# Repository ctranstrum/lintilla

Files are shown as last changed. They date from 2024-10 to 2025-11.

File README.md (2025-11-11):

# Lintilla Keyboard

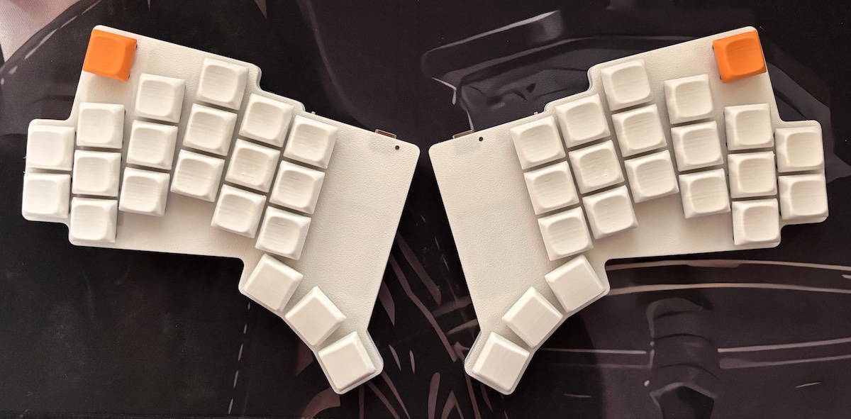
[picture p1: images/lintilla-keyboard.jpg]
Lintilla Keyboard


## Features

- 42 key wireless split ergo keyboard with aggressive pinky stagger, splay, and "reachy" thumbs
- Seeed Studio [XIAO BLE][xiao] microcontroller
- Choc v1 hotswap switches
- "Relaxed" (18.5x18) choc spacing: a compromise between MX (19x19) and choc (18x17)
- 7mm low-profile "snug sandwich" case with no exposed components on top or bottom
- [RGB LED status][rgbled] visible on the top of the case
- Wireless-first design using [ZMK][zmk] [firmware][firmware] (including [ZMK Studio][studio])
- Jumperless [reversible](images/pcb-allitnil.jpg) [PCB](images/pcb-lintilla.jpg) designed with [ergogen][ergogen]
- Soldering is simple: SMD components all on a single side of the board for each half
- Internal space (5.4 x 24 x 34 mm) for a "large" 502030 250mAh battery
- Licensed under the [CERN Open Hardware License v2][ohl]
- All source files available, so you can tweak the design if needed

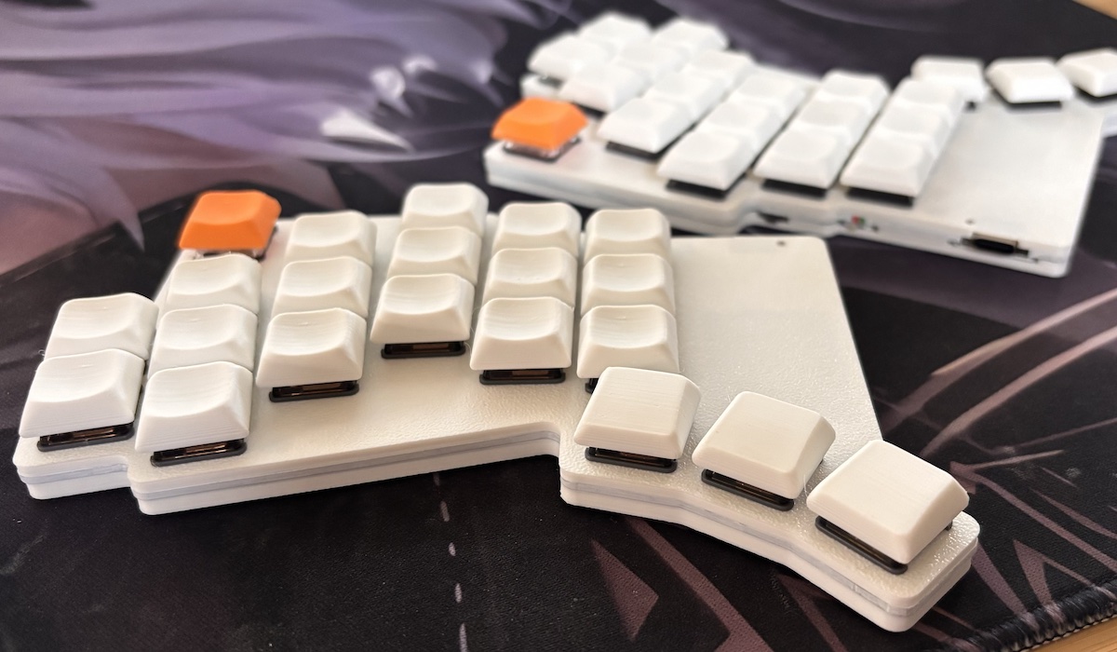
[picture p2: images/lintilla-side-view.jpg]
Lintilla side view


## Design goals

- Low cost wireless
  - xiao ble is only $10 per controller compared to $25 for the nice!nano
  - Reversible PCB for the cheapest manufacturing option (I ordered a set of 5 boards, the minimum order, for under $10)
  - Big battery and an option for a dongle, so you can [run for months without recharging][batteryestimate]
- Ergonomic design for the ultimate comfort
  - split keyboard means you can place each half where it best works for you
  - keys are placed where (my) fingers at rest naturally fall
    - when fingers extend, they splay, so the keys also splay outward to follow the fingers
    - the pinky is shorter than the other fingers, so the pinky keys are placed lower to match
    - unlike most ergonomic boards, the thumb doesn't have to tuck below the palm to reach the thumb keys
  - includes all source files, so if your fingers are slightly different, with a little work you can adjust the keyboard to fit you exactly
- Low profile 3D printable case
  - case is only 7mm high and each side comes in two separate pieces, each largely flat on one side for easy FDM printing with minimal fuss
  - bumpons are inset into the case 1mm to minimize their height; they add only 1/2mm in height
  - choc v1 hotswap switches are some of the shortest commonly available
- Hotswappable
  - keycaps and switches can be easily removed and exchanged so you can fine tune the feel
  - the case is designed to hold tight to the switches, while offering a switch-puller groove that allows for safe and easy removal
- Electrostatic protection
  - unlike other ultra-low-profile cases, no electronics are exposed on either the bottom or the top of the case
  - on the side of the case, the reset button and power switch are available, and the usb port is accessible

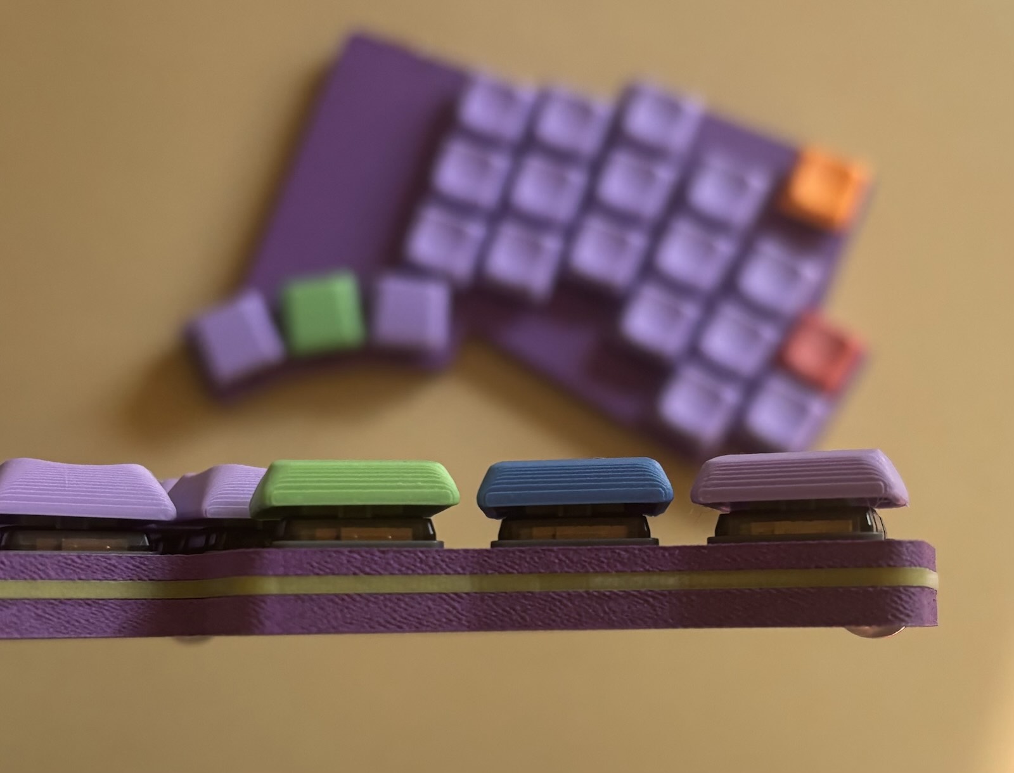
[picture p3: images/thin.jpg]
low profile case


## Build Your Own

Think the Lintilla might be right for you? Print out the [fit guide][fitguide] to see how it feels under your fingers.

Want to build one? You will need to obtain the following components:

| Qty | Description |
| --- | --- |
| 2 | identical [Lintilla PCBs][pcb] (can be printed by uploading the [zip file][pcb] to [JLC][jlc]) |
| 4 | [3D printed cases][case], top and bottom for each half |
| 2 | [XIAO BLE][xiao] processors |
| 2 | [Panasonic EVQ-PUC02K momentary switches][reset] for the reset button |
| 2 | [Alps SSSS811101 SPDT slide switches][power] for the battery on/off |
| 2 | [3.7v 250mAh 502030 rechargeable LiPo batteries][battery] (max internal space: 5.4x24x34mm) |
| 42 | SOD-123 [1N4148W SMD diodes][diodes] |
| 42 | Kailh [Choc Hot Swap Sockets][sockets] |
| 42 | [Choc v1 switches][switches] of your choice |
| 42 | [Choc v1 keycaps][keycaps] of your choice (note: full MX-sized keycaps will be too big) |
| 8 | [M2 hex nuts][hexnuts] |
| 8 | [M2 x 6mm countersunk screws][screws] |
| 8 | [6mm x 1.5mm bumpons][bumpons] |
| ~5-6mm | [1.75mm transparent 3D printer filament][filament] for the "fiber optic" led light guide |

Once you have these items, you can follow the instructions in the [Build Guide][buildguide].

## Firmware

After you build the keyboard, you will need the [ZMK firmware][firmware].

## What's this about a dongle?

The Lintilla keyboard, with its [LED indicator][rgbled], is perfectly capable of running without a dongle.
With a 250mah battery, the central half should last about 2 months between charges, and the peripheral about 4-6 months.

Some people prefer to use a [dongle][dongle], though, both to allow both halves to last longer between recharging,
as well as to provide additional feedback on the battery and bluetooth status and currently active layer and modifiers.

I have tested the Lintilla with the following dongles, though you should be able to get any ZMK-compatible dongle to work with it:

- The fancy [Prospector Dongle][prospector]
- The more traditional [OLED Dongle][oled]

Note that while the Lintilla keyboard uses the XIAO BLE as its processor, you can use any bluetooth-capable ZMK-compatible processor
on the dongle. If you found a dongle you like, but it uses the nice!nano processor, for example, it should work just fine with Lintilla.

## Credits and inspiration

- [ZMK][zmk]: for the firmware
- [Ergogen][ergogen]: for the tools to quickly iterate over the design
- [Ergonaut One][ergonautone]: for the elegant approach to a xiao-based reversible PCB
- [Klor][klor]: for the almost-perfect key layout

## Descendants

After I used the Lintilla for about three months, I realized that for me, the design had a few flaws:

- The case can bend a bit on the outside edge of the controller; an extra screw there would have helped with that
- Constantly adjusting the location of each split half as I moved around while typing was annoying
- I felt like the layout had too many keys intended for use by the pinky, causing pain after long typing sessions
- My thumbs aren't smart enough to use three keys each; I kept pressing the wrong thumb key, even after three months of use

To address these concerns, while still preserving the basic structure of the Lintilla key layout,
I designed the [Charlieflex keyboard][charlieflex], an ergonomic unibody keyboard with between 30 to 32 keys.

I've been using a 31-key version of Charlieflex for over half a year now, and I'm very happy with it.

## In the wild

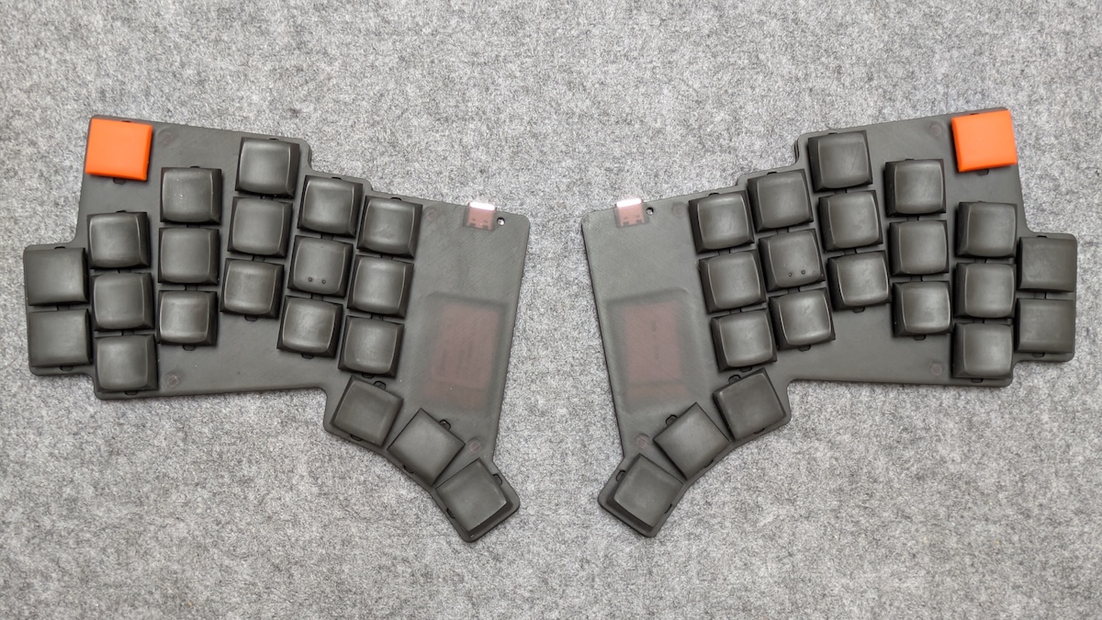
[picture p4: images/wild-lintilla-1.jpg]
first Lintilla in the wild


cairn's Lintilla build, using JLC Black Resin for the case, with Nocturnal switches and Chicago Steno keycaps.

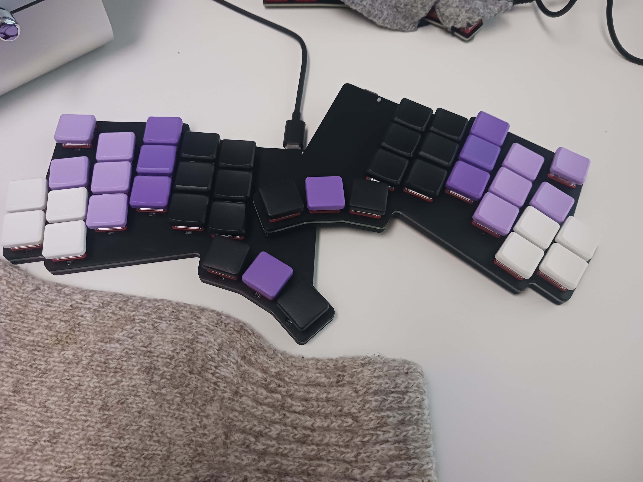
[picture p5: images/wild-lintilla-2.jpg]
kovas's Lintilla


kovas's Lintilla, see some more details and pictures on [his website](https://kovasap.github.io/docs/lifestyle-optimizations/keyboards-and-typing/#lintilla).

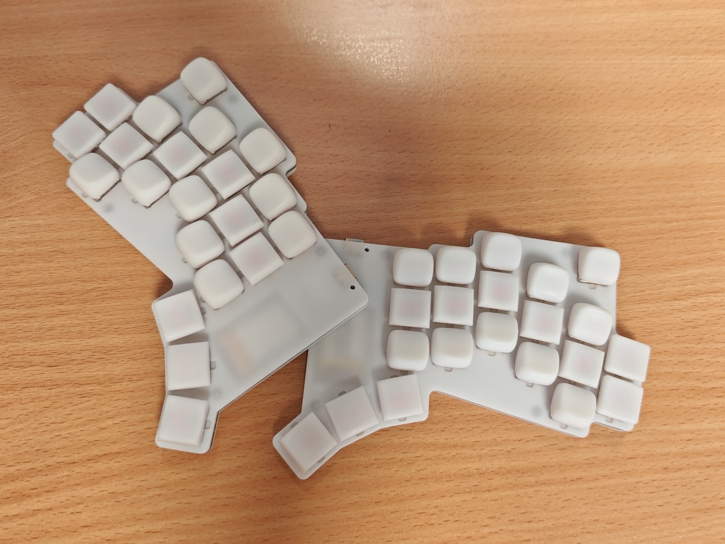
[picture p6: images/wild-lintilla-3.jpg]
Kris' Lintilla


Kris's Lintilla.

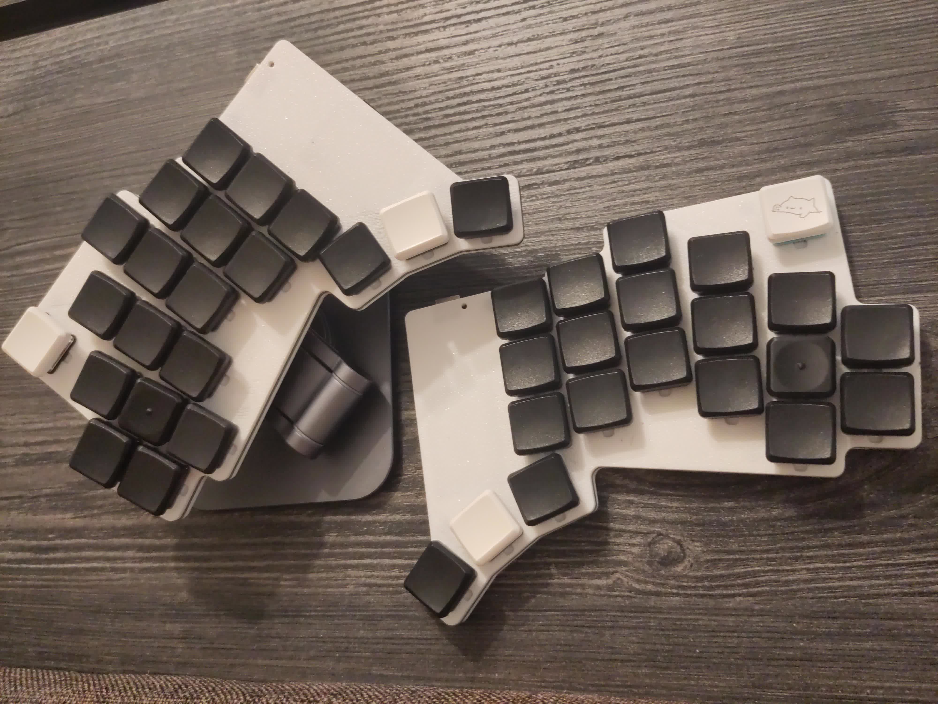
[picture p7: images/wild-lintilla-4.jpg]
Optional's Lintilla


Optional's Lintilla, read some more details on [her blog](https://blog.optional.page/misc/better-keyboard#interlude-my-experience).

---

Did you build a Lintilla? Send me a photo, and I'd be glad to feature it here.

[battery]: https://ydlbattery.com/products/3-7v-250mah-502030-lithium-polymer-ion-battery
[batteryestimate]: https://zmk.dev/power-profiler
[buildguide]: BUILD.md
[bumpons]: https://www.walmart.com/ip/Small-Door-Bumpers-Self-Adhesive-Clear-Rubber-Feet-Tiny-Bumpons-1-4-Diameter-X-1-16-Thick-100-Pack-u2026/2377364014
[case]: cases/
[charlieflex]: https://github.com/ctranstrum/chuck
[diodes]: https://typeractive.xyz/products/smd-diodes
[dongle]: https://zmk.dev/docs/development/hardware-integration/dongle
[ergogen]: https://ergogen.xyz
[ergonautone]: https://ergonautkb.com/docs/keyboards/ergonaut-one/intro/
[filament]: https://gizmodorks.com/nylon-filament-200-g-spool/
[firmware]: https://github.com/ctranstrum/lintilla/tree/zmk
[fitguide]: images/fit-guide.pdf
[hexnuts]: https://www.getfpv.com/m2-black-metal-hex-nut-set-of-8.html
[jlc]: https://jlcpcb.com
[keycaps]: https://lowprokb.ca/collections/keycaps/products/ldsa-low-profile-blank-keycaps
[klor]: https://github.com/GEIGEIGEIST/KLOR
[ohl]: LICENSE.txt
[oled]: https://github.com/englmaxi/zmk-dongle-display
[pcb]: pcb/lintilla-gerbers.zip
[power]: https://typeractive.xyz/products/power-switch
[prospector]: https://github.com/carrefinho/prospector
[reset]: https://typeractive.xyz/products/reset-button
[rgbled]: https://github.com/caksoylar/zmk-rgbled-widget
[screws]: https://monsterbolts.com/products/mach-phil-flat-a2-m2?variant=21222571802707
[sockets]: https://typeractive.xyz/products/hotswap-sockets?variant=45742200324327
[studio]: https://zmk.dev/docs/features/studio
[switches]: https://lowprokb.ca/collections/switches/products/ambients-silent-choc-switches
[xiao]: https://wiki.seeedstudio.com/XIAO_BLE/
[zmk]: https://zmk.dev

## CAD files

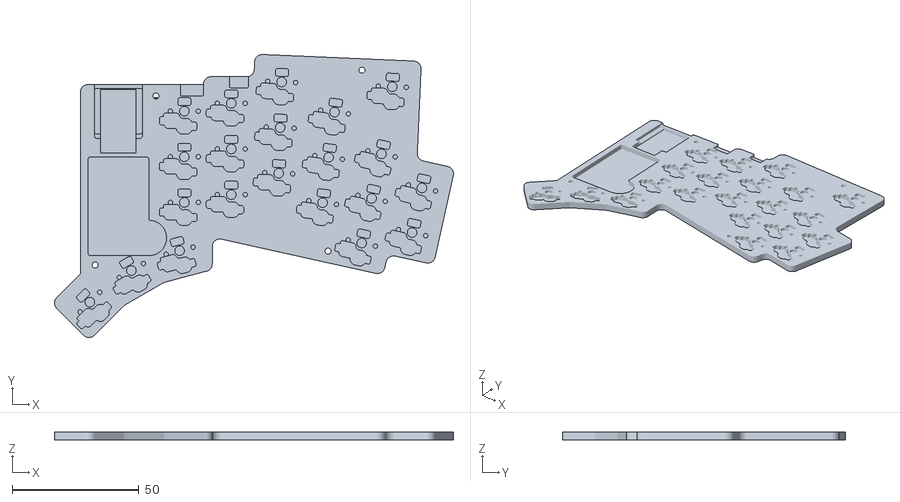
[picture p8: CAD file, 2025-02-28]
cases/bottom_right.stl
157.3 x 111.6 x 3.20

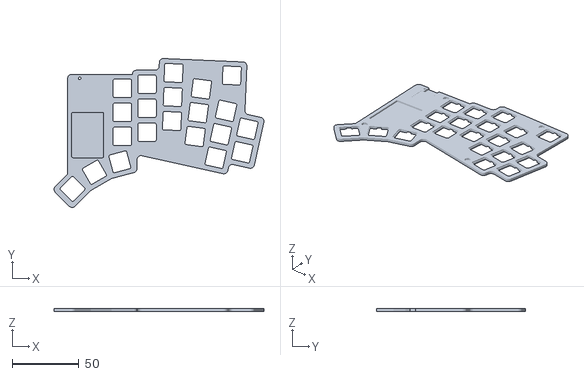
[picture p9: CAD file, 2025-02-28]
cases/top_left.stl
157.3 x 111.6 x 2.20

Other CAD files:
cases/top_left_reverse.stl
cases/top_right.stl

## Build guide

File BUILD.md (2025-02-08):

# Lintilla Build Guide

If this is your first time building a custom keyboard,
you should do two things before attempting this build.

- watch a few [soldering][how-to-solder] [tutorials][soldering101]
- read through a detailed build guide like
  the one for the [splitkb.com Aurora Series][splitkb-build-guide]

The remainder of this build guide will assume a basic familiarity with the process
and will only hit upon specific items that may be different or important to note while
building the Lintilla.

## Useful equipment

You should ideally have access to:

- a [soldering iron][pinecil]
- some [good quality solder][kester]
- a decent hands-free magnifying glass
- precision tweezers
- wire cutter / stripper
- isopropyl alcohol and an old toothbrush

## Getting the PCB

The PCB can be easily ordered from a circuit board manufacturer with an online store.
I used [JLC][jlcpcb] because--at least at the time of my order--their prices are unbeatable.

To order, you can simply upload the [gerber zip file][gerber] to their website,
accept all of the defaults, and wait a week or two for the boards to arrive.

Since the PCB is reversible, in theory you could order just two of them, and you'd be able
to build a complete keyboard. However, the minimum order at JLC is 5 copies, so you'll likely end up
with enough PCBs to complete two and a half keyboards. I don't really have any advice for what to do with
half a keyboard, but if you make two keyboards, you could give one to a friend!

A few items that you may want to customize:

- the color of the board; I printed mine in white, but whatever color you pick, the edges of the PCB will still be a little greenish
- you can choose to hide the JLC order number, or place it on the board where I've included the required order number string
- HASL can be lead-free if you are also using lead-free solder, or you can splurge for ENIG, but it's definitely not required

## Printing the case

If you don't have access to a 3D printer, you can also print your case at [JLC][jlc3dp].
I've had complicated boards printed in "Imagine Black" resin before, and been very impressed with the results.

However, I designed this case to be easy to print yourself on an FDM printer at home.
I printed mine using PLA, but you may want to consider PETG if you are planning to travel with
the keyboard and may at some point leave it in a hot car.

The case comes in [four separate files][case], a top and bottom for each half.

There are a few spots on the case where there is a small overhang that could cause problems on an untuned printer.
This is for the bumpon indentations on the bottom of the case, and for the switch-puller access on the top of the case.
I chose to enable supports for these sections, and had to gently remove the extra support material after each print,
but I felt like the print had higher quality this way.

## Soldering the components to the PCB

Once you've got your PCB and your components in hand, the exciting part of building can begin!

### All components are soldered on the same side of the board

Unlike many other custom keyboards, the Lintilla is designed so that all components are
soldered on the **bottom** of the circuit board. This makes the top of the board as low profile
as possible and makes it easy to know where each component goes.

While the PCB is reversible for the lowest cost manufacturing,
the silkscreen on the top of the board is different from the bottom,
so that when you are soldering components on the side labeled "Lintilla"
you are working on the right half of the keyboard,
and when you are soldering components on the side labeled "Allitnil"
you are working on the left half of the keyboard.

| Lintilla (right half) | Allitnil (left half) |
| --- | --- |
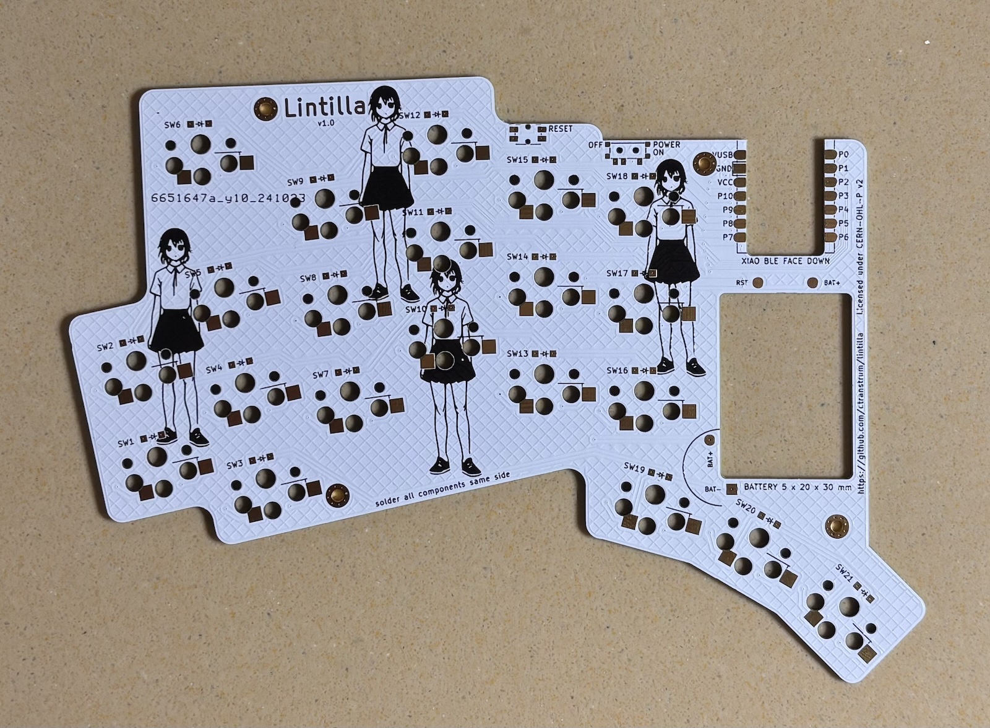
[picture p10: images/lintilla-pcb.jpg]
Lintilla
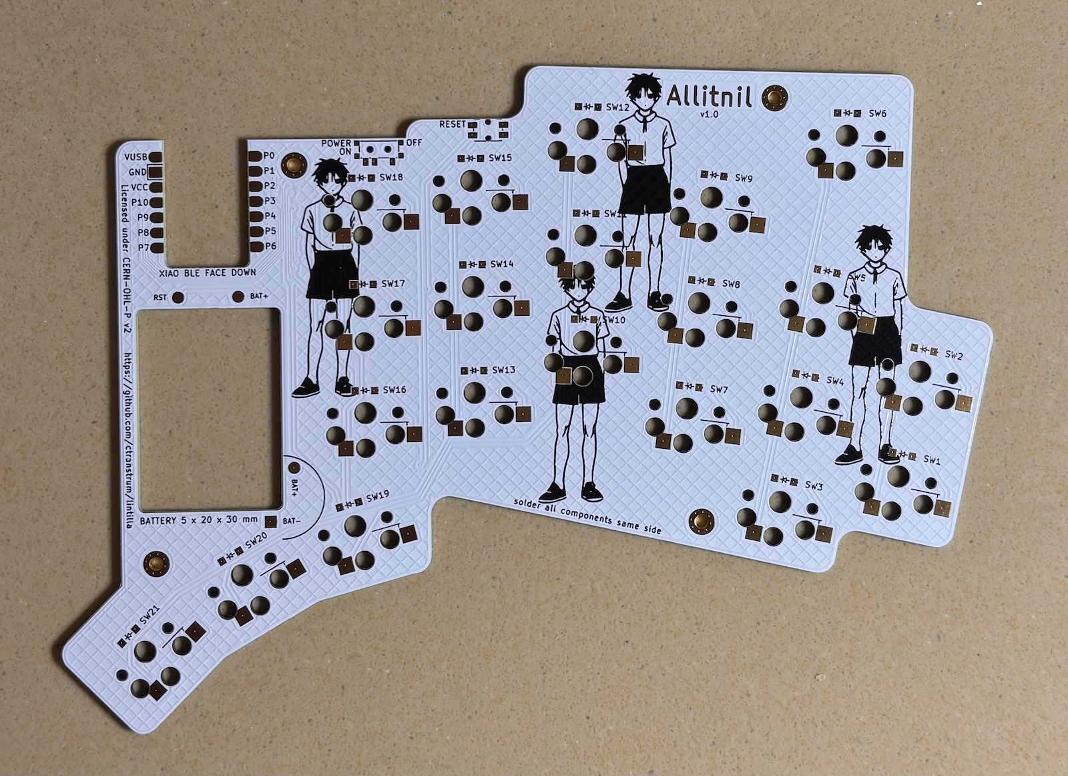
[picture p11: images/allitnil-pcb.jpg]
Allitnil
|  |  |

### Diodes only work one direction

Start with the diodes. Note that diodes only work in one direction,
so it's important that you align the line on the diode with the silkscreen line
on the PCB. It can sometimes be hard to see the line on the diode, so you may have
to look at it under a magnifying glass and/or with the light striking the diode at
an angle to see it well.

All the diodes are oriented the same way on each half of the PCB. That is to say,
when you are soldering on "Lintilla", all the lines on the diodes will be on the right,
and when you are soldering on "Allitnil", all the diode lines will be on the left.

| Lintilla diodes | Allitnil diodes |
| --- | --- |
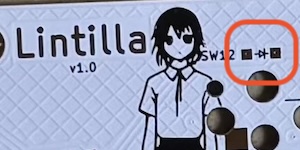
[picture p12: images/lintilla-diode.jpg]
Lintilla diode alignment
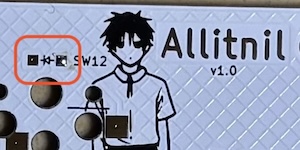
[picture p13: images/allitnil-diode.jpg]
Allitnil diode alignment
|  |  |

To solder a surface mount diode, I find it easiest to first add a little solder to one
of the pads on the PCB, then using a pair of tweezers move the diode into position as I
reheat the solder, and then remove the soldering iron while still holding the diode in
position so the solder can cool. Once I am satisfied that the diode is correctly in
place and flat against the PCB, I then solder the other leg of the diode.

Note that for the case to fit properly, it is important that each diode be centered in
its position and flat against the board. If it is too far out of position or sitting at
an angle on the board, the case may not fit.

### Hotswap sockets also need to be aligned

Next step is the hotswap sockets. Although electrically they will work even if installed
the wrong way, in order to ensure that the case fits correctly,
it is important to look at the line on the silkscreen and align the hotswap
socket so that the corner with the right angle is oriented to the line on the PCB.

In the following picture, the blue box on SW19 shows the silkscreen line before
a hotswap socket is installed, the green box on SW20 shows a hotswap socket in the
correct orientation where the silkscreen line is mostly hidden by the straight lines of
the top edge of the socket, and the red box on SW21 shows an incorrectly oriented
hotswap socket, where the silkscreen line is clearly visible poking out around the
angled edges of the socket.

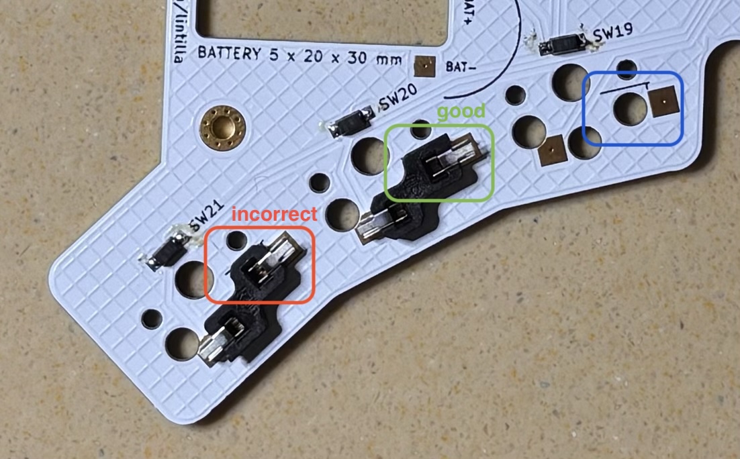
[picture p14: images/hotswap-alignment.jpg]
hotswap socket orientation


To install a hotswap socket, set the socket into place in the PCB, double check the alignment, and
then heat one pad and feed solder into the hollow of the socket until it's pretty much filled up, noting that
the hotswap socket will take a **LOT** more solder than used for the diodes. Repeat for the other leg.
Note that you need to be careful not to use so much solder that it flows outside of the socket footprint,
while still ensuring that you still have enough to allow for a strong bond to form,
which will help provide strength to the socket for inserting and removing the switches,
If you use too much solder so that it spills out of the socket, the case will not fit correctly.

### Power switch and reset switch

The power and reset switches are very similar. The PCB has tiny holes to help with the alignment
of these switches, and just like with the SMD diodes, the trick is to start with a little solder
on one of the pads, then use tweezers to keep the switch in place and/or fix its alignment
while reheating the solder. Once one leg is firmly in place and the alignment is correct, you can
solder the remaining legs.

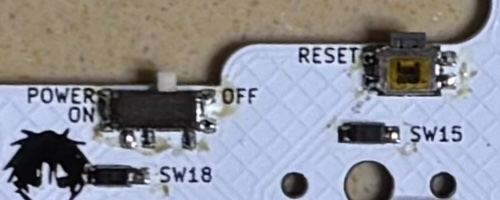
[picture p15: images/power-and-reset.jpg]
power and reset switches


Note that the four legs on the left and right edges of the power switch are not electrically important; they
serve to provide strength to the switch to withstand the pressure of turning the switch on and off.
So if you accidentally join these legs together with solder, you don't need to try to remove the joining solder.

For the reset switch, however, it is important that the top and the bottom legs do not have a solder bridge.

Again note that while there is a little extra space around the pad for the solder, in order for the case to fit
correctly, it is important that you do not have too much extra solder going outside of each pad or above the switches.

Once you have soldered the power switch onto the board, make sure to leave it in the "OFF" position for the duration
of the soldering. Note that when the power switch is pushed toward the microcontroller, it is "ON"
and when it is pushed away, it is "OFF".

### Microcontroller

Now that all the other components are soldered to the board, it is time to address the microcontroller.

The board has been designed so that the majority of the height of the microcontroller is using the same vertical
space as the PCB itself, so it's a bit unconventional, but the microcontroller needs to be soldered upside down to the board.

Note that the height of the components on the XIAO is higher than the thickness of the PCB,
so in order for the XIAO to lay flat during the soldering process, the PCB will need to be placed on something flat
with the place where the XIAO sits extended off over the edge so that there is room for the XIAO.
I used some of the extra PCBs for this, simply stacking two spare PCBs below the one I was soldering.

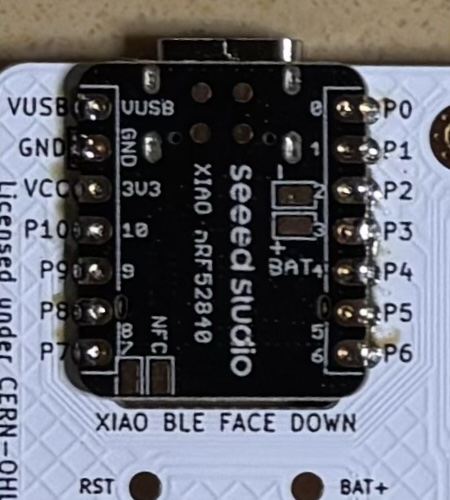
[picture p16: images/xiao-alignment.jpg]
XIAO Microcontroller


The alignment of the microcontroller is a little tricky.
There are lines on the PCB where the XIAO edges should go,
but getting it to stay in place while soldering it is a bit of a challenge.
My technique is similar to that of a diode:
put a little solder on one of the corner pads of the PCB,
and use tweezers or a finger (far from the heat of the soldering iron!)
to steady the board while reheating the solder.
I usually have to do this three or four times to get the board perfectly aligned.
While there is a little leeway on an exact fit,
you should take care to get it as close as possible.
The top edge of the XIAO should be even with the edge of the PCB,
and along both sides of the XIAO you should be able to see an equal amount of each pad sticking out.

Once one corner is soldered and the alignment is looking good,
solder the opposite corner to firmly fix it in place,
and then solder each remaining pad one by one,
placing the tip of the soldering iron on the visible portion of
the PCB pad and against the side of the XIAO's castellated pad.
Take care not to allow the solder to spill out of the side of the pad or above the XIAO,
but you should be able to see solder coating the bottom of the pad through each hole in the XIAO,
and it's okay if that solder fills up some of each hole as well.

### Battery

Now for my least favorite part. First double check that the switch is in the "OFF" position.
Place the battery into the battery cutout with its wires pointing toward the semicircle
in the silkscreen. That semicircle indicates the amount of room available for the wires.

You will need to cut, strip, and solder the battery wires to the board. When cutting the battery wires:

- cut and solder one at a time (you do not want the exposed portion of the wires to touch or you will destroy the battery)
- put electrical tape over any exposed wire you aren't working on, for extra precaution
- leave enough length to get a little bend in the wire, but not so much that the wire goes outside the semicircle, as shown in the picture
- keep the remaining wire after it's cut; you'll use it on the next step
- make sure to solder the red wire to BAT+ and the black wire to BAT-

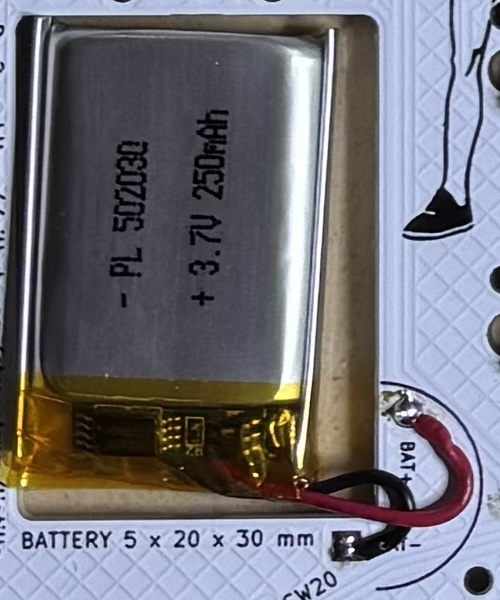
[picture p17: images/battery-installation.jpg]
battery wire soldering


Then, with the remaining wire that was cut from the battery,
connect the pads on the underside of the XIAO to the pads on the PCB.

Be very careful to cut these wires to the exact length needed.
You don't want them too long. And too short is also obviously not going to work.
I speak from experience here.

Both the XIAO and the PCB have a silkscreen for the BAT+ wire. However, the XIAO does not have any mark for the RST pad.

The reset pad on the XIAO is the lower right pad of the four circular pads near the USB port.

When connecting these wires, try to go straight up from the PCB onto the back of the XIAO before going left or right.
The bluetooth antenna is located in the lower middle section of the XIAO,
and a wire there could slightly interfere with the bluetooth signal.

Also note that the XIAO BAT+ and BAT- pads are **really** close together, and you don't want to bridge these,
so be extra careful when soldering the BAT+ pad, and don't turn the power switch back on until you are certain
you haven't inadvertently connected these two pads.

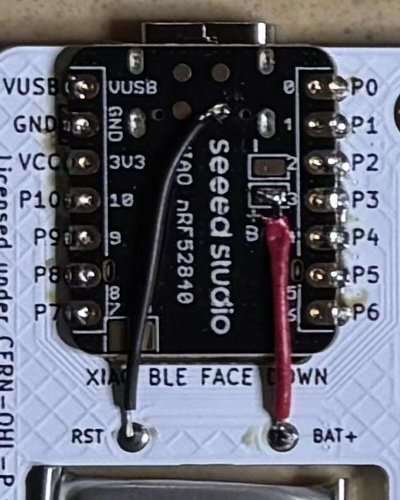
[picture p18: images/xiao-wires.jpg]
xiao back pad wires


### Clean the flux

Now that all the components are soldered onto the board and the battery is connected, take a moment to admire your work,
then clean the flux from the board using an old toothbrush and some isopropyl alcohol. It doesn't have to be perfect.

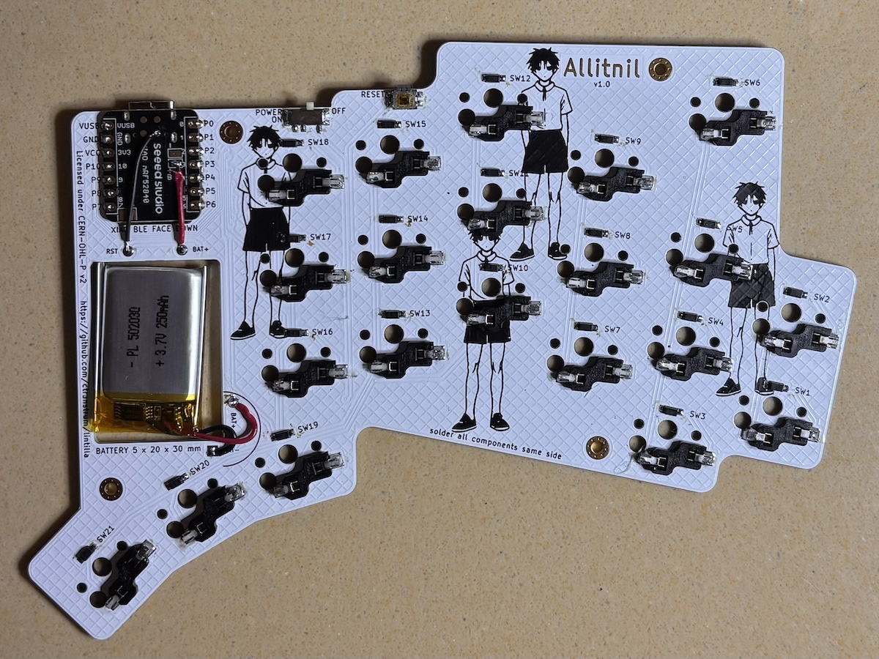
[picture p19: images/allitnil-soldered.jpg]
Allitnil soldered and cleaned


Also take a moment to examine each solder joint
to ensure that you don't have extra blobs of solder
that might interfere with the case.

If you do, you can remove these with a clean soldering iron and a little soldering wick.

Flip the board over and make sure no solder sneaked through any of the vias.
If it did, a moment with a hot iron can clean these up as well.

## Assemble the PCB into the case

Now it's time to put the case together! You're almost there!

### Slide the "fiber optic" light guide in place

Take the section of translucent printer filament and slice a tiny section about 2.5 to 3mm in length.
This can be hard to do because it's so tiny and it will try to fly away and hide in the carpet or behind a bookshelf.
I speak from experience.

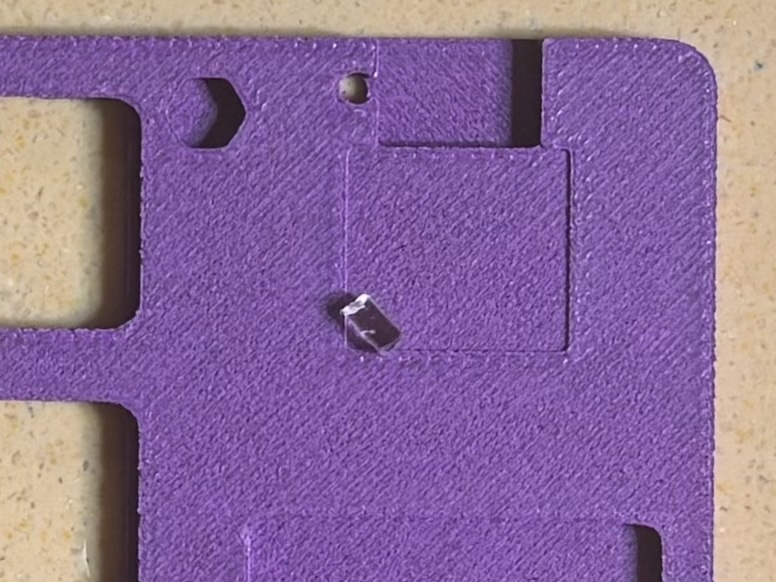
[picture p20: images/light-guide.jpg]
filament cut and ready for insertion


Once you have this piece cut (and you still know where it is), use a pair of tweezers to coax it into the hole in the top case.

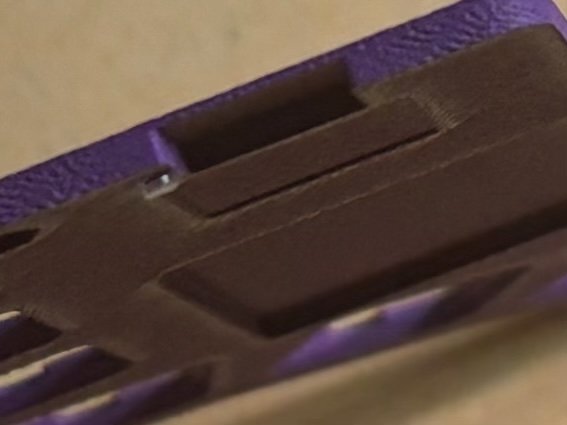
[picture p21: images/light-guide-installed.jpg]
filament in place


It should extend out a little bit below the case, and if it pokes out a bit above the case as well, that's okay, too.
When the case is fully assembled, you can push down gently on it to get it as low as possible.
On my board, it sticks up about a quarter of a millimeter, and that allows the light to be very visible.

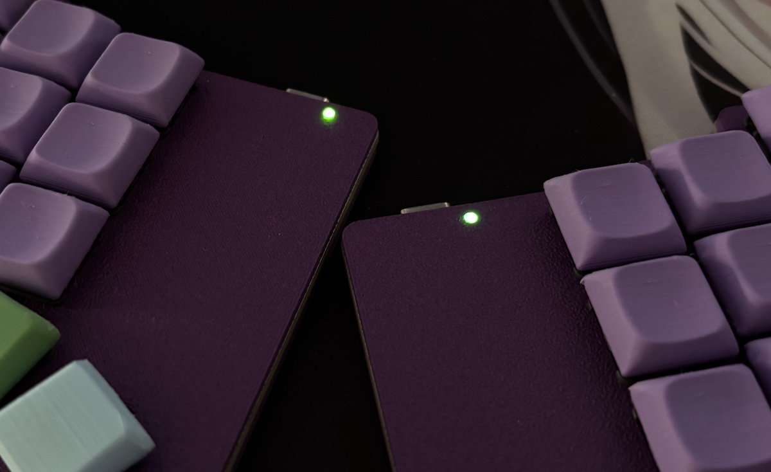
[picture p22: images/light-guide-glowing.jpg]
filament in action


### Use the nuts and screws to assemble the case to the PCB

Place the four nuts into the cutouts in the top case.

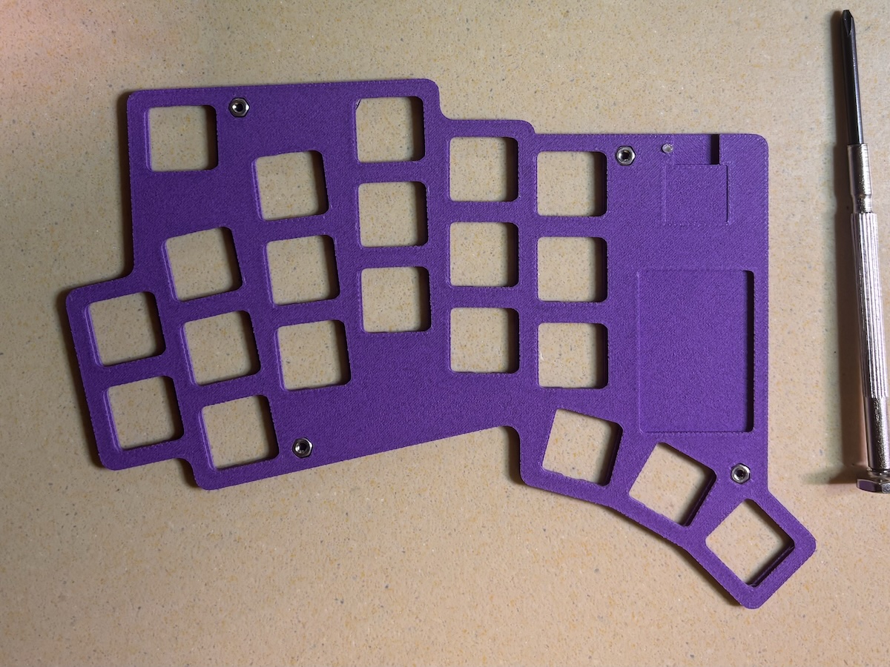
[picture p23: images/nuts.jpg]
nuts in place


Then place the PCB onto the case, components facing away from the top case, and align the edges.
The xiao and the battery should slide easily into the hollows prepared for them and help with alignment.
Put the bottom case on top, and use four screws to secure it to the PCB.

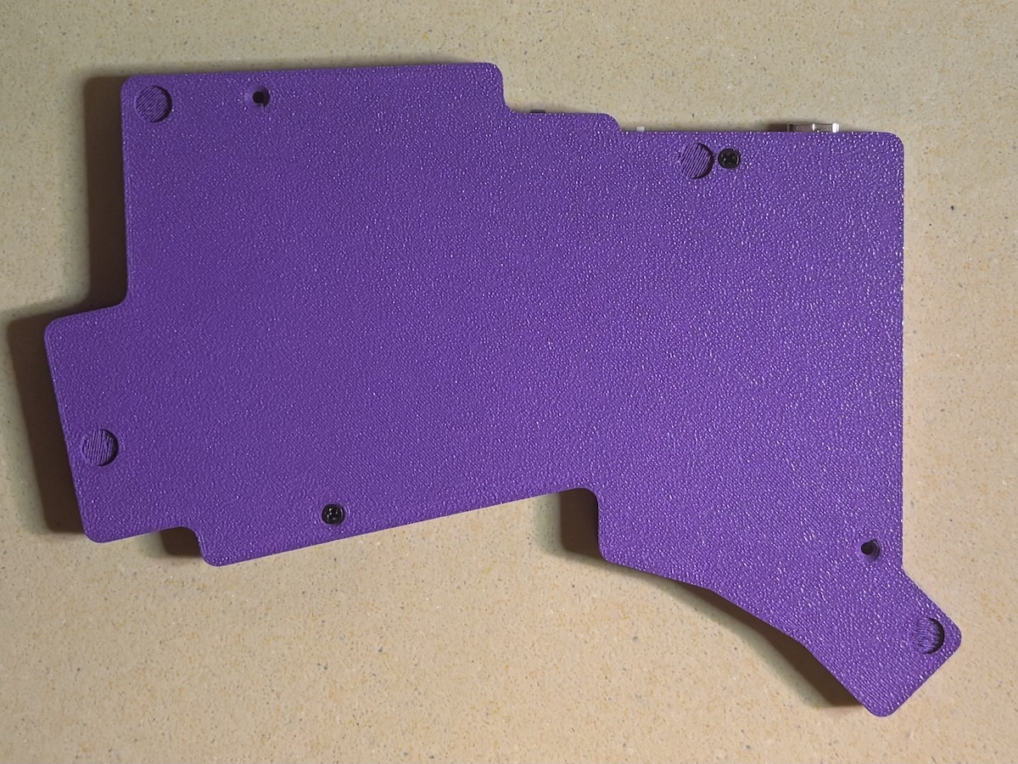
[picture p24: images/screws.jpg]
screw the bottom on


At this point, the bottom of the case is attached to the PCB,
but the top of the case is only held in place by the pressure
of the slight twisting of the nuts as you attached the screws,
and it may be possible for it to be removed at this point.

Flip the case over. If the top comes off, simply put it back in place.

### Insert the switches and keycaps

Then insert the switches. The switches actually attach to the PCB rather than the top case,
so the switches will serve as the "screws" to keep the top plate attached.

Take care when inserting the switches that the pins of each switch are straight.
Gently place the switch in place, and position it so it is aligned before pushing it
straight down. Do not try to assemble it at an angle. It may take a bit of force to get the
switch fully seated. There should be no gap between the skirt of the switch and the top plate.

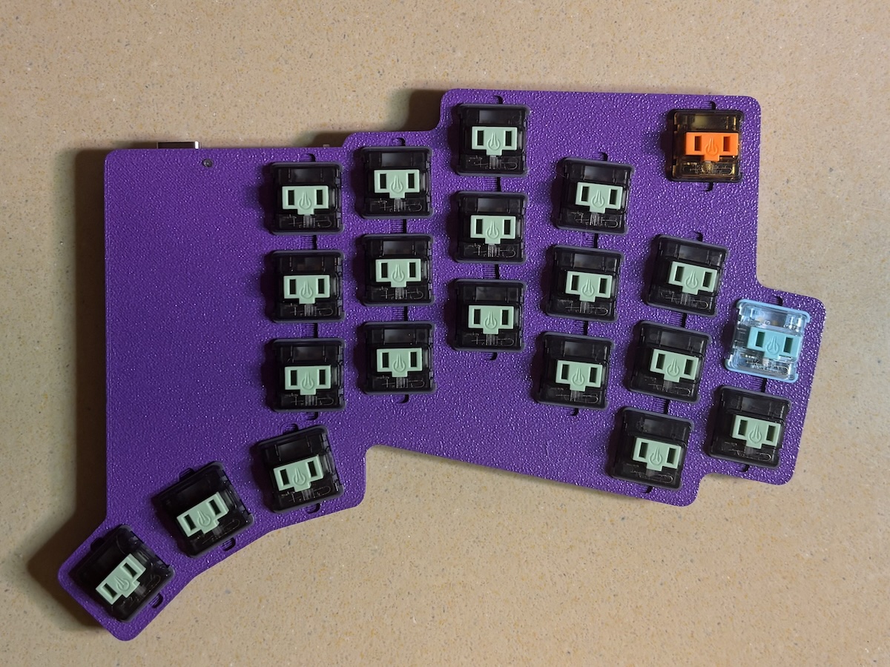
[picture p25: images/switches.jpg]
switches installed


Attach the keycaps. Again, try to first align the keycap and then use firm even pressure.

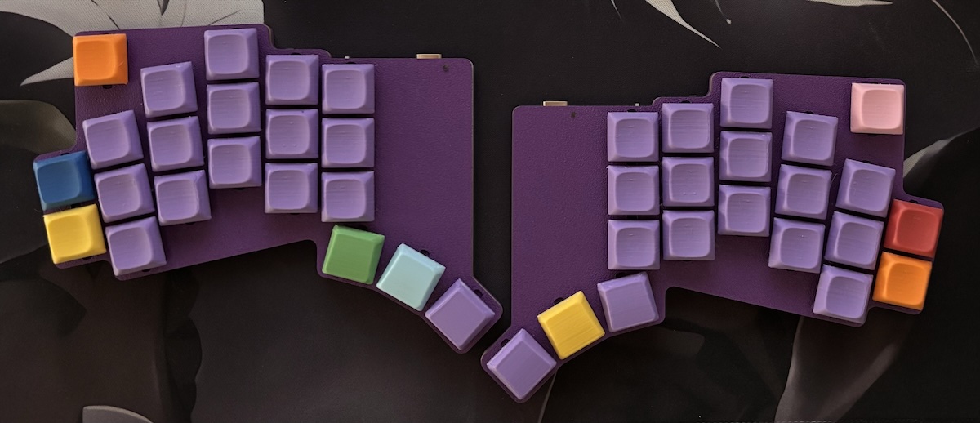
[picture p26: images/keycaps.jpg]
keycaps installed


### Attach the bumpons

Once everything else is installed, flip the keyboard back over and press each bumpon into place
in its designated spot. Your keyboard is now ready for firmware.

## Firmware installation

You can grab the default firmware from the [firmware repository][firmware].

To install it, attach each half one at a time to the computer by USB, double-tap the reset button,
and then drag the firmware for that half to the device that appears as a thumb drive.

drag and drop to install

Note, however, that the "thumb drive" is not actually a real thumb drive, and normal copy and paste operations
do not work as they do on a real thumb drive. Copying the file to the keyboard is really a command to the
microcontroller to install firmware. As soon as the firmware is installed, the keyboard will reboot and start
running the new firmware. This will make the "thumb drive" immediately disconnect from the computer, which
is often seen as an error by the operating system.

ignore read/write error

But you are free to ignore that error and just start using the keyboard. Just don't try to copy anything that's
not a firmware to the keyboard, and you should be fine.

## Problems?

For more information about using [ZMK][zmk], including how to use [ZMK Studio][zmkstudio],
or how to configure your own [zmk repo][zmkrepo], please refer to the [ZMK docs][zmkdocs].

If you still have the default keymap installed and want to update the layout with [ZMK Studio][zmkstudio],
the "ZMK Studio unlock" key combination is accessed by two keys on the right half of the keyboard:
hold down the extra key on the top right side (mapped by default as the MUTE key)
and then press the middle thumb key (mapped by default as the SPACE key).
Note that you will need to be using Chrome or Edge to get it to work.

If a key isn't working, the first thing to look at is that the switch has been installed properly,
and the pins aren't bent.

If you need to correct any soldering,
access to the bottom of the PCB is as simple as removing the four screws on the case.
You do not necessarily need to remove all the switches.
However, if you are doing extensive re-soldering work,
it may be a good idea to fully remove the PCB from the case.

One unexpected feature of the XIAO microcontroller is that the power switch must be "ON"
in order for the battery to charge while plugged into a USB-C cable.
Remember: sliding the power switch toward the USB port turns the keyboard on,
while sliding it away from the USB port turns it off.

[case]: cases/
[firmware]: https://github.com/ctranstrum/lintilla/tree/zmk
[gerber]: pcb/lintilla-gerbers.zip
[how-to-solder]: https://www.google.com/search?q=youtube+how+to+solder
[jlc3dp]: https://jlc3dp.com/
[jlcpcb]: https://jlcpcb.com/
[kester]: https://typeractive.xyz/products/kester-solder-wire-tube
[pinecil]: https://typeractive.xyz/products/pinecil
[soldering101]: https://www.google.com/search?q=youtube+soldering+101
[splitkb-build-guide]: https://docs.splitkb.com/product-guides/aurora-series/build-guide
[zmk]: https://zmk.dev/
[zmkdocs]: https://zmk.dev/docs
[zmkrepo]: https://zmk.dev/docs/user-setup
[zmkstudio]: https://zmk.studio/

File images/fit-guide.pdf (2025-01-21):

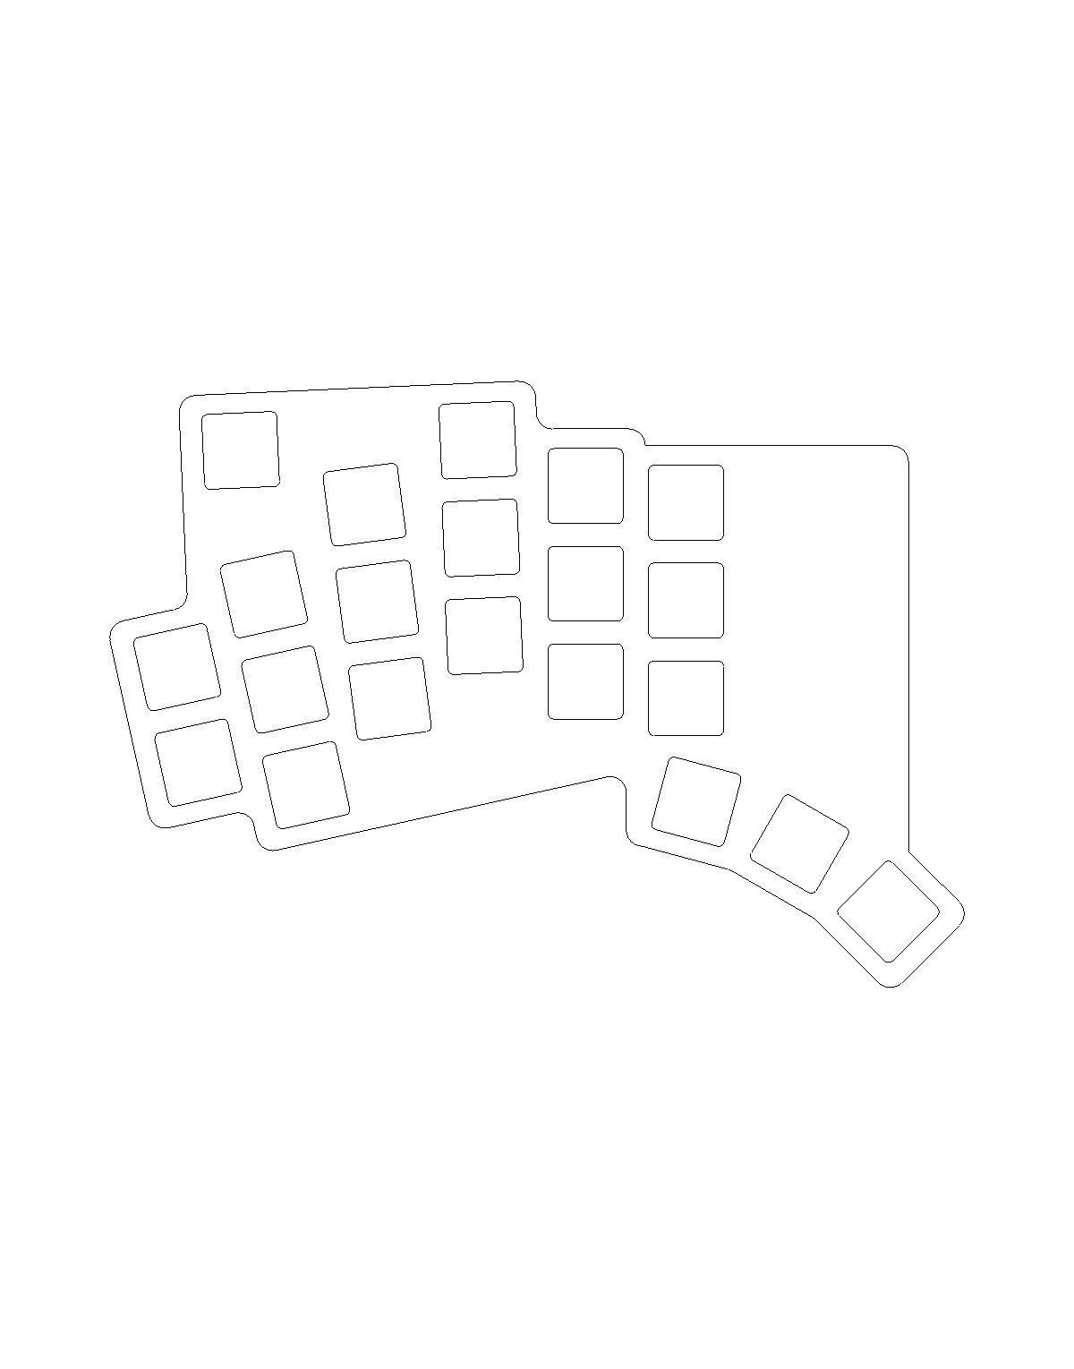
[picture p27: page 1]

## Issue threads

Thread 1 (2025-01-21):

Printable layout image/diagram?

kovasap, 2025-01-21:
I'm super excited to have found this design (via https://www.reddit.com/r/ErgoMechKeyboards/comments/1i6q9ih/searching_for_keyboard_42_key_split_staggered/) and am strongly considering building it!

Before I do, do you know of a way for me to print out the layout on a piece of paper (like you can do from https://compare.splitkb.com/) so that I can double check that it will fit my fingers?

ctranstrum, 2025-01-21:
If you have KiCad, you can download the PCB file and print it out at 100% size. I also just added a quick little PDF at https://github.com/ctranstrum/lintilla/blob/main/images/fit-guide.pdf that should work much the same.

kovasap, 2025-01-21:
Amazing thank you!  This design looks to fit me very well :)

ctranstrum, 2025-01-21:
Glad to hear it. Sounds like you and I both had the same issues with other existing board designs.

peterjc, 2025-04-21:
Could you add a scalebar to https://github.com/ctranstrum/lintilla/blob/main/images/fit-guide.pdf easily? I don't entirely trust my printer ;)

5cm / 2inches seems common

ctranstrum, 2025-04-22:
Oh, that's a good idea. Let me take a look at that.

Closed 2025-01-21.

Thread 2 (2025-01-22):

Battery Life and Alternative Battery Options

kovasap, 2025-01-22:
I'm curious what battery life you usually get with your 250mah batteries.  The description says "months" but it's unclear to me if that involves a separate "dongle" battery pack.  Also, how long does it take to fully recharge them?

I ask because I'm considering just buying https://typeractive.xyz/products/lithium-battery-110mah, as they are cheaper than alternatives (given I'll be already ordering from typeractive and bundling shipping).  I'd like to estimate how much life I'll get on these in comparison to the 250mah batteries in the bill of materials.

ctranstrum, 2025-01-22:
I built two Lintillas about two month ago, and popped the batteries in at that time. Other than very short periods where I connected the keyboards to the USB cable long enough to flash the firmware on them, I have never fully charged any of the four halves. I have a dongle set up on one of the two pairs, and I use one set at work and the other at home, so potentially I use them less than if I just had the one keyboard. But for my dongle set, one half is still showing at just under 40% and the other at 70%, and for my non-dongle set, the master is reporting about 45%.

I would think you could get a fair amount of use out of a 110 mah battery. The best (but still imperfect) estimator can be found at https://zmk.dev/power-profiler and with 110mah, it estimates about a month on a non-dongled central and about three months on a peripheral.

kovasap, 2025-01-22:
Thanks for the info!  After doing some reading I finally now understand what a dongle actually is 😅 .  Did you follow a particular build guide to create your dongle?

ctranstrum, 2025-01-22:
Not exactly a build guide, no, but the fancy Prospector Dongle is here: https://github.com/carrefinho/prospector and the more traditional OLED dongle here: https://github.com/englmaxi/zmk-dongle-display. I've used both of those, but to be honest I've found that the rgbled-widget the Lintilla uses is, for my needs at least, almost as useful as the dongles, and I find myself preferring to run in it dongle-less.

Closed 2025-01-22.

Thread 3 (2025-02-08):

Changing tolerance on case?

kovasap, 2025-02-08:
I just finished soldering my lintilla, and went to place it into my 3d printed case.  Sadly it does not fit neatly because (I'm pretty sure) that some of my hotswap socket soldering blobs are too big.  I was concerned to make them super strong when soldering, but think I overdid it.  FWIW the blobs are not taller than the sockets, but simply wider.

AFAICT, the easiest way to fix this issue is to re-3d print the case, but with larger tolerances around the hotswap soldered sections.  When you created the case files, did you use a particular method to define the hotswap section outlines and set tolerances I could emulate?

I could also try to grind down the case somehow, but figured others may run into this problem too and a laxer case doesn't seem to have any downsides?

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

ctranstrum, 2025-02-08:
Haha, yeah you really overdid it with those connections. :) I'm not sure I want to make the tolerances as big as you'd need, and there's really no way for me to know which of the solder blobs is the largest without doing a little measuring, but you're correct that it probably won't hurt too much to increase the sizes of the cutouts for the sockets.

The fastest way is for you to do it yourself. If you clone the repo, you can edit the `config.yaml` file to give yourself more room, then re-run ergogen, and look in the outputs/cases folder for the new stl files. The lines to look for to edit would be lines 401 and 450 for the room around the sockets, currently set to half a millimeter of tolerance all the way around, then lines 783 and 791 for how high to make the hole, currently set to 2mm, though for the height, you can probably re-melt the solder to push it a little more flush, since the height of the hole is going to be more troublesome than the other setting due to the already thin nature of the case.

If I had to guestimate, I'd say to increase the `expand` settings to 1.5 and the `extrude` to 2.4.

It looks like the other components are probably okay, do you get the impression anything other than the sockets are having trouble fitting?

ctranstrum, 2025-02-08:
Ah, just re-read that the solder doesn't extend above the sockets. That's encouraging. I can give more room around the sockets, and I'll look at the other components as well while I'm in there.

ctranstrum, 2025-02-08:
Okay, I've just updated the case with a little more room around all the components. In particular, I bumped the space around each socket from .5mm to 1mm. I'd rather not go more than that because it makes the edge walls really thin, but you can always edit a copy yourself if you feel you need more and are okay with the thin walls that would result from that.

kovasap, 2025-02-08:
Amazing thank you!  I will try it out next week!

On Sat, Feb 8, 2025, 6:55 AM Chad Transtrum ***@***.***>
wrote:

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

kovasap, 2025-02-11:
The new case works perfectly!  Thank you!!

On Sat, Feb 8, 2025 at 8:39 AM Kovas Palunas ***@***.***>
wrote:

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

ctranstrum, 2025-02-11:
So glad to hear that!

Closed 2025-02-08.

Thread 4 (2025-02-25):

I put the xiao on the wrong side - desoldering ideas?

kovasap, 2025-02-25:
Hey i'm back again after finally getting my xiao microcontrollers!

I just went to finalized my build by soldering the xiaos and my batteries.  Unfortunately, I soldered them on the wrong side :(.  And I did both sides of the keyboard before double checking :(((

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

I managed to remove one by grilling it on a hot plate at 350F, but I'm pretty sure that destroyed my microcontroller:

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

A friend mentioned that the keyboard might still work with the controller on the wrong side (with some changes to the case), but I would rather just redo it correctly.  Do you happen to have any ideas as to how to remove the xiao without destroying it?

Worst case I can just grill the other side and get two new controllers.

Also sorry for all the github issues; if there's a better forum for this please let me know!

ctranstrum, 2025-02-26:
Ouch, yeah, my advice for removing an smd-soldered xiao would be to use hot air while the xiao is upside down so that as soon as the solder is liquid it will fall off; that would reduce the amount of heat to the absolute minimum. There's no guarantee, though, that the xiao would survive the ordeal, but that's probably the most likely to work.

Your friend is correct. Though the case would no longer fit without modification, electrically the xiao would still have all the correct connections on this board if installed on the wrong side.

It looks like removing the xiao also lifted some of the pads off the pcb, but that doesn't necessarily mean that the xiao is dead or that the pcb won't work with a working xiao soldered to the other side.

There is a dev board firmware you can flash to the xiao to see if it's working or not, though I don't have a link nor can I offer any help with that process. But if you want to try to google it, you may still be able to salvage one or more of the xiaos.  If the xiao is still working, you can use more flux and solder to remove the pcb's pads from it, and then solder it to the correct side. But as you said, a new xiao will be the more certain bet.

kovasap, 2025-02-27:
Today I tried the heat gun approach for the other xiao microcontroller and it worked really well!  I covered the controller with foil, put the whole board upside down, then heated one side at a time with the heat gun while pushing firmly from above with tweezers.  The first side came off cleanly, with the other side bending to allow separation.  Then the other side was easy to remove in the same way.  Any the xiao still works!

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

kovasap, 2025-02-27:
I've now assembled the entire keyboard and everything seems ok so far, although i still need to test all the switches.  Will send pictures of the final product!

ctranstrum, 2025-02-27:
Oh! That's a relief to hear! Nice job! Can't wait for final pics!

Closed 2025-02-26.

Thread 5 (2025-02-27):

Viewing a wiring diagram

kovasap, 2025-02-27:
If it hasn't become abundantly clear by now, I'm still somewhat new to building keyboards 😅 .  My build is coming along nicely, but on one of my boards, two of the keys do not work:

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

I suspect that one of the connections to the microcontroller is not solid, or perhaps one of my diodes/sockets is not soldered properly?

What's the best way to view a wiring diagram of the board so that I can figure out which soldering jobs I need to check for these two keys?

ctranstrum, 2025-02-27:
One of the main weaknesses of the ergogen-based approach to creating keyboards is that it doesn't create a wiring diagram. All of the information for a wiring diagram is present in the `config.yaml` file, but not in a format as easily digestible as a wiring diagram. Those two keys are using P4 as the column pin and from top to bottom P3 and P2 for the row pins. Since they are both not working, my guess would be that you have a problem with the connection to P4 on the MCU.

ctranstrum, 2025-02-27:
One thing you can test is taking a pair of tweezers and touching P4 to P3 and then P4 to P2 to see if they trigger that way. If that works, then the MCU is still good, and you just need to find where it doesn't get back to P4 correctly. If shorting the pins doesn't work, then you may have a bad pin on the mcu.

kovasap, 2025-02-27:
Yep, my P4 was not soldered correctly.  I just added some more solder to that pin and it works now!

ctranstrum, 2025-02-28:
So glad to hear that! I'm really happy you didn't ruin either of your xiao's in the desoldering process. 😄

kovasap, 2025-02-28:
Haha well the one that i removed via frying pan was ruined, but I had a 3 pack :).

ctranstrum, 2025-02-28:
Ah, yeah, I was really surprised when I had thought the xiao lived through your first desoldering attempt. Well, thankfully you had the spare!

Closed 2025-02-27.

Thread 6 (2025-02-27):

Case tolerance feedback

kovasap, 2025-02-27:
FEEL FREE TO IGNORE THIS FEEDBACK!  (as any open source feedback)  I intend it as just info, not as a request for help or something blocking my build that I need to figure out.

One thing I noticed with my build is that the upper inner corner of the case sandwich doesn't fit flush and can splay out.  For one of my sides, this is certainly because of sloppy soldering (and using a controller that was removed and reattached, with extra solder sticking around on it).  But it is present on the other side as well.  This issue is exacerbated by the absence of a screw on the inner side of the controller.

It may be worth considering giving a bit more vertical tolerance for the microcontroller where the soldering happens to reduce this effect.

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

ctranstrum, 2025-02-27:
This is something I found on my builds as well, though not quite as pronounced as you are seeing, and is definitely something that bugged me enough that I used a LOT more screws on my subsequent keyboard design.

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

If you don't mind removing the case and trying to get a good picture of how high the solder goes on the back of the mcu, that might help. While I can't add a screw to that location without making some major redesign choices, I can update the case files fairly easily, since they are auto-generated, and maybe we can add a bit more to the tolerances around the solder points of the mcu, like we did for the sockets. A side view picture would probably show it best.

kovasap, 2025-02-27:
Actually, upon further inspection, it looks like my pcb may be slightly warped, perhaps due to the hot air station use to get the xiao off.  Additionally, it seems like my xiao is just uniformly vertically shifted up when compared to the other side, likely because of the extra solder that was already on it from the first application.

I'm not sure what would help for my situation in terms of case changes.  But I do think generally giving a tiny bit more vertical space for the xiao would make the case more fool-proof.

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

ctranstrum, 2025-02-28:
Yeah, it's hard to tell from the photo if the pcb is warped, but I trust you if you say it is. What I find interesting is that on my builds, it seems to fit just fine on the top of the pcb, where there is no solder, but the bottom case bends away at that corner, whereas on yours it's the top case that is also bending away, or is that the warp of the pcb I'm seeing?

I had prepared some changes to allow a little room for solder above the mcu (or, since it's soldered upside down maybe I should say below it), but that doesn't look likely to alleviate your issue at all now that I see what you are saying about the solder creating space between the mcu and the pcb. My case dimensions assume the mcu is installed flush to the pcb.

kovasap, 2025-02-28:
I think that is the pcb warp you are seeing.

Thanks!  Those changes may still be helpful in general.

I'm pretty ok with the current state of my build, this issue isn't very noticeable unless i'm looking for it.

ctranstrum, 2025-02-28:
Gotcha. Updated the cases with increased tolerance for small solder blobs above the microcontroller. I doubt it will help much with your issue, but I agree it's a good idea.

Closed 2025-02-28.

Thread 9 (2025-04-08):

3d printing case question

ntnrmr, 2025-04-08:
I came over this keyboard and think that I like the layout and number of keys. This will be my first build and I decided to use jlc services to print both the pcb and the case. While pcb has been approved, review of the case got some yellow alerts and I've received subsequent email from the service asking to adjust the model. Could you offer some advice on that matter? Are this errors safe to ignore?

Also I can see that in their model viewer, halves have some weirdly looking red areas which I suspect might be a bug of some sort

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

ctranstrum, 2025-05-08:
Thanks for the update. Sounds like you had similar results, though maybe slightly worse, to mine. What material did you choose to print?

Closed 2025-05-07.

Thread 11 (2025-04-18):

Help with firmware?

behlersyeg, 2025-04-18:
Hey, so I had a working version of the firmware, and was even able to edit the first layer to make it Colemak, but then somewhere along the way, the new firmware stopped working so I tried to start over and see if I could get back to a working version of the original keymap.

No matter what I try, I can't get the two halves to pair. Dropping in older firmware, and the connect, no problem.

Can you take a look at my repo and let me know what I missed?

https://github.com/behlersyeg/zmk-config

ctranstrum, 2025-04-18:
So, a couple of things about zmk firmware to take into consideration.

1. Almost all connectivity problems are resolved by flashing a settings reset file to the boards and then starting again. https://zmk.dev/docs/troubleshooting/connection-issues
2. The zmk project is a live project and every once in a while they accidentally break things and newly compiled firmware won't work until they unbreak it. Luckily this is fairly rare and is usually fixed within a few days.
3. I actually made a few changes to the Lintilla firmware myself in the past few days and had one issue I wasn't sure what to do about, so maybe it was me that broke it. My issue was on dongle code, though, so I'm not sure it would affect you.

I can take a look, sure, but if the code is compiling and you are getting firmware out of it, I may not be the best person to help. You may have better luck talking to smarter people on the zmk discord server.

ctranstrum, 2025-04-18:
Looking at your repo, the current code looks to be compiling correctly, but it also looks not to have Colemak, so when you say going back to older code, do you mean a) reflashing a firmware you compiled a few weeks ago? or b) restoring files to their old version, recompiling, and then flashing that new firmware to the board?

behlersyeg, 2025-04-18:
I meant more option B). I nuked the old repo and started over. I knew it worked with the default keymap, so I am just retracing my steps.

I'll try going through the zmk connection issues with a fine tooth comb again, I guess! Thanks for the tips and context and I'll keep trying!

One small piece of feedback, it may be useful to have a more basic "default" keymap without all the heavy modifications. For example the default Corne is just three layers with basic &kp inputs and loads of white space. I personally find it a bit easier to customize something from the ground up, than tear stuff down and rebuild on top. But that's just a small thing that has more to do with the learning curve going from VIA to ZMK, hah hah.

ctranstrum, 2025-04-20:
How is the process going? Have you made any headway on this?

Thanks for the feedback. My standard layout uses like 9 layers and Colemak as the base keymap, so this was my attempt to simplify, LOL, but I'll take another look and see if I can pare it down even more.

ctranstrum, 2025-04-20:
Eh, I finally had a chance to look at my most recent firmware changes, and found a mistake that probably was the sole cause of your issues. I fixed it just moments ago, and now all my firmware is compiling successfully. I bet it will now work for you as well.

ctranstrum, 2025-06-03:
Closing this issue since there has been no activity on it for over a month, but feel free to open a new issue if you continue to have problems building the firmware.

Closed 2025-06-03.

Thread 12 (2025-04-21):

Troubleshooting non-working switches

otherdave, 2025-04-21:
Hi! Thanks for this project. I saw you post in another issue with advice on the pins to check for some bad switches. Any chance you've got some more advice to spare?

The right-side works perfectly. The left side however....

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

All of the missing switches are ones that don't work.

(One of them was a badly soldered diode, but I forget which exactly)

I have shorted some of the pins on the controller together - I DO get keypresses there (I got the pins from the other issue you commented on since one of those keys overlapped with one of mine not working)

In case it's relevant, I realized today that my controller appears to always be on. If I turn the switch from off to on, nothing happens. If I plug in the usb-c cable, even when the switch is off, it turns on. I just realized that earlier today and haven't had a chance to check & re-solder the switch and check the controller. But I'm mentioning it here in case it's helpful.

My planned next steps are to remove & re-solder the switch and then re-re-re-check the controller and make sure everything is soldered correctly.

ctranstrum, 2025-04-21:
Regarding switches not working, the best troubleshooting guide I have seen is by splitkb. I don't think I can give better troubleshooting advice than what is already written so well there. https://docs.splitkb.com/troubleshooting/key

Unfortunately when you use ergogen to create the keyboard, it does not automatically create a wiring schematic, so if you need to know which pin connects to which switch, you will need to dig into the file named config.yaml to see if you can figure it out. I can help with that process if needed.

It's not entirely intuitive how the switch works. The switch only affects whether or not the battery and the controller are connected. So when the USB cable is unplugged, the switch determines whether the controller gets electricity and powers on. But when the USB cable is inserted, the controller will get power via USB and turn on regardless of the position of the switch. However, in that case the battery will not charge until the switch is moved to the on position.

otherdave, 2025-04-22:
Thanks so much for the advice / info! The `config.yaml` wasn't that scary after all, but it turns out I didn't need it. I re-soldered all of the connections to my controller and things just magically worked! I suspect the ground was a really bad joint and then there may have been a few others that just weren't making contact at all / consistently. So I gave them all a look & reflow or more solder. I touched up a few diodes that looked suspect just to be sure and things are great!

I'm glad I went through the yaml file, it was fun to learn a bit more about how this is put together.

Thanks again for the help and for Lintilla.

ctranstrum, 2025-04-22:
Glad to hear it! Marking this as closed.

Closed 2025-04-22.

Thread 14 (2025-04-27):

Add info.json, Miryoku layout

OptionalM, 2025-04-27:
To use the [Keymap Editor](https://nickcoutsos.github.io/keymap-editor/), an `info.json` is required. I already generated one [here](https://github.com/OptionalM/zmk-config/blob/Miryoku_v1.0/config/lintilla.json).

Would you be willing to add it to this repo? It would've saved me some time to have it here already.
___
Also, I've built something close to the default flavor of the popular [Miryoku layout](https://github.com/manna-harbour/miryoku).
The compiled firmware is attached to [this release](https://github.com/OptionalM/zmk-config/releases/tag/Miryoku_v1.0), and the config can be accessed [here](https://github.com/OptionalM/zmk-config/tree/Miryoku_v1.0).

Would you link (either of) these? Again, it would've saved me some time to have a firmware that is more familiar.
___
Finally, just a big "thank you" for this board! It was fun to build and I love many of your design decisions. I'm a bit unsure, though, about how far out the thumb keys are. Especially coming from the very tight corne, it's a huge difference. I'll need more time to figure out if I get the hang of it, or if I have to mod a version where they're more tucked in.

I'll also open a PR with a picture soon though!

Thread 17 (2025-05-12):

Using a different reset switch

sinefabula, 2025-05-12:
Hi! First of all, great case design! I think all popular keyboards should be upgraded to your case design :)

Anyway, I'm planning to build this keyboard but I can't order those reset buttons from typeractive (as they don't ship to my country in the EU) and ordering from Mouser (or similar) would cost a lot. Can the reset button be replaced with something else with the same footprint? Or I have to update the PCB and the case to make it fit? If so, do you by chance have any guidelines on how to modify these? From my understanding, you're using some JS library for parametrised modelling and PCB design? Also, this could be helpful for those wanting to adjust the position of the thumb cluster.

Edit: I meant not 'power switches' but 'reset buttons'.

ctranstrum, 2025-05-12:
Thanks for the positive feedback. The reset buttons can be replaced with another momentary button that has the same footprint, sure. A lot of people shop on chinese websites that have very low prices for electronics components, though sometimes shipping can take longer. There's not really anything special with the switch I've recommended over any other that matches the dimensions.

As far as making changes to the footprints, this project is using ergogen to make everything relatively easy to adjust. While there is a learning curve involved with it, ergogen can allow you to update any part of the keyboard, from the reset button to the thumb cluster, as you have mentioned.

I should also point out that a reset switch in not strictly necessary for the keyboard. The reset button does two things: press it once to restart the firmware, or double-tap it to enter firmware flashing mode. You will need to double-click the reset button the first time you flash the firmware onto the board. You can do that directly on the xiao before the case is installed. After that, as long as you dedicate a key somewhere in your keymap that will allow the board to enter flashing mode, you will not need to use a reset button. If you need to reboot the firmware at any point, using the power switch to turn it off and then on again will restart the firmware.

ctranstrum, 2025-07-03:
Closing this issue, since there has been no activity on it for more than a month.

Closed 2025-07-03.

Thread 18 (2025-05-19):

choc v2 switch compatibility

thanhdat77, 2025-05-19:
Thanks for your work
Can i ask is it fit chocv2, i heard that the center footprint in v2 is a bit bigger

ctranstrum, 2025-05-19:
You heard correctly. Choc v2 require a larger center hole than choc v1. Unfortunately, I designed this only for choc v1. So no, this board is not compatible with choc v2 switches. Sorry.

thanhdat77, 2025-05-20:
Sorry to bother you, but I’ve already bought the Choc V2 switches and keycaps. I was wondering — do the keyboard have MX-compatible spacing? And if not, would it be possible to modify the plate by enlarging the holes?

ctranstrum, 2025-05-20:
It's no bother. The spacing between keys is not standard MX. Instead, it's halfway between standard MX and standard choc spacing. Since it doesn't take choc v2 switches, I've never actually tried it with MX keycaps, so I can't say for sure that it doesn't work, but I would be inclined to think that it won't fit.

My newest keyboard design uses MX spacing and accepts both choc v1 as well as choc v2 switches, and it has the same splay that the Lintilla has, but it's definitely not a Lintilla. If you want to take a look at it, you can find it at [github.com/ctranstrum/chuck](https://github.com/ctranstrum/chuck).

If you can't find a keyboard design you like other than the Lintilla, you can always edit the Lintilla files to modify the spacing and add the choc v2 footprints, but that is a fairly difficult project if you've never created your own keyboard before, so you may be better off, if you want to go that route, of designing your own board to your exact specifications.

Closed 2025-07-03.

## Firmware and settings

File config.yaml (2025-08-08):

meta:
  author: chad@transtrum.net
  version: &version v1.0
  repository: &repo https://github.com/ctranstrum/lintilla

  # Depending on where you are ordering from, uncomment or edit one of these:
  order_num_template: &order_text JLCJLCJLCJLC # for ordering from JLCpcb.com
  # order_num_template: &order_text WayWayWay    # for ordering from PCBway.com
  # order_num_template: &order_text ""   # remove the order number text completely

units:
  $default_spread: (u + cx) / 2
  $default_padding: (u + cy) / 2
  $default_height: cy
  $default_width: cx

  # distance between keys
  dx: (u + cx) / 2
  dy: (u + cy) / 2

  # distance to the line between keys
  hdx: dx / 2
  hdy: dy / 2

points:
  zones:
    matrix:
      # Shift the PCB down and to the right to get it on the sheet in kicad
      anchor.shift: [50, -100]
      key:
        tags: [key]
      columns:
        outer:
          key:
            splay: 12.5
            colpin: P4
          rows:
            bottom:
              tags: [key, bumper_left]
              rowpin: P2
            home:
              rowpin: P3
        pinky:
          key:
            stagger: -dx * 0.45
            colpin: P8
          rows:
            bottom:
              bind: [5, 50, 0, 0]
              rowpin: P1
            home:
              bind: 0
              rowpin: P2
            top:
              bind: 0
              rowpin: P3
            fn:
              orient: -10
              shift: [0, 8.9]
              bind: [0, 25, 20, 0]
              tags: [key, bumper_left]
              rowpin: P10
        ring:
          key:
            stagger: dx * 0.66
            splay: -5
            colpin: P6
          rows:
            bottom:
              rowpin: P2
            home:
              rowpin: P3
            top:
              rowpin: P10
        middle:
          key:
            shift: [0.2, 0]
            stagger: hdx
            splay: -5
            colpin: P9
          rows:
            bottom:
              rowpin: P2
            home:
              bind: 0
              rowpin: P3
            top:
              rowpin: P10
        index:
          key:
            stagger: -hdx
            splay: -2.5
            colpin: P7
          rows:
            bottom:
              rowpin: P2
            home:
              rowpin: P3
            top:
              rowpin: P10
        inner:
          key:
            stagger: -dx / 6
            colpin: P5
          rows:
            bottom:
              bind: [5, 24, 16.76, 0]
              rowpin: P2
            home:
              rowpin: P3
            top:
              bind: [0, 5, 5, 5]
              rowpin: P10
              tags: [key, bumper_right]

    # thumb zone
    thumb:
      key:
        tags: [key]
        rowpin: P1
      anchor:
        ref: matrix_index_bottom
        shift: [0, -dy - 1.5]
      columns:
        tucky.rows.spot:
          skip: true
        secondary.rows.spot:
          splay: -15
          origin: [-cx / 2, -cy / 2]
          colpin: P9
          bind: [0, 1, 0, 0]
        primary.rows.spot:
          splay: -15
          origin: [-cx / 2, -cy / 2]
          colpin: P7
          bind: [0, 1, 0, 1]
        reachy.rows.spot:
          splay: -15
          origin: [-cx / 2, -cy / 2]
          colpin: P5
          bind: [0, 0, 0, 1]
          tags: [key, bumper_right]

    # component zones
    mcu:
      anchor:
        ref: matrix_inner_top
        shift: [26, 0]
        #columns.xiao.rows.ble:
      key:
        tags: [mcu, component]
        bind: 10

    battery:
      anchor:
        ref: matrix_inner_bottom
        shift: [26, 1]
        #columns.compartment.rows.cutout:
      key:
        tags: [battery, component]
        bind: 10

    reset_button:
      anchor:
        ref: matrix_index_top
        shift: [-3, cy / 2]
      key:
        tags: [reset, component]

    power_button:
      anchor:
        ref: matrix_inner_top
        shift: [-3, cy / 2 + 0.05]
      key:
        tags: [power, component]

    screw_top_left:
      anchor:
        ref: matrix_pinky_fn
        shift: [hdx + 3, hdy - 3]
      key:
        tags: [screw, hardware]
    screw_bottom_left:
      anchor:
        ref: matrix_pinky_bottom
        shift: [hdx + 3, -hdy + 3]
      key:
        tags: [screw, hardware]
    screw_top_right:
      anchor:
        ref: matrix_inner_top
        shift: [hdx + 2, hdy - 3]
      key:
        tags: [screw, hardware]
    screw_bottom_right:
      anchor:
        ref: thumb_primary_spot
        shift: [hdx + 2, hdy]
      key:
        tags: [screw, hardware]
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

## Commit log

2024-09-28 initial version
    [lintilla-B_Cu.gbr, lintilla-B_Mask.gbr, lintilla-B_Paste.gbr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]
2024-10-17 update case
2024-10-21 add hotswap tool groove to top case
2024-10-24 add transparent filament to the bom
2024-10-24 fix bom table
2024-12-03 add battery cavity size in BOM
2024-12-03 add wire cutter and isopropyl alcohol to list of tools
2024-12-14 add explanation for importance of socket orientation
2025-01-22 link to zmk sources for dongles and the power profiler
2025-02-08 Give a little more room around soldered components so the case still fits after aggressive soldering
    [bottom_right.stl, top-left.stl, top_left.stl]
2025-02-28 adjust case tolerances
    [bottom_right.stl, top_left.stl]
